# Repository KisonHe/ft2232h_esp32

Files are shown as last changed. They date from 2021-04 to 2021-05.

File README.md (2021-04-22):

# ft2232h_esp32

How to use make this tool?

1. First, get your PCB.
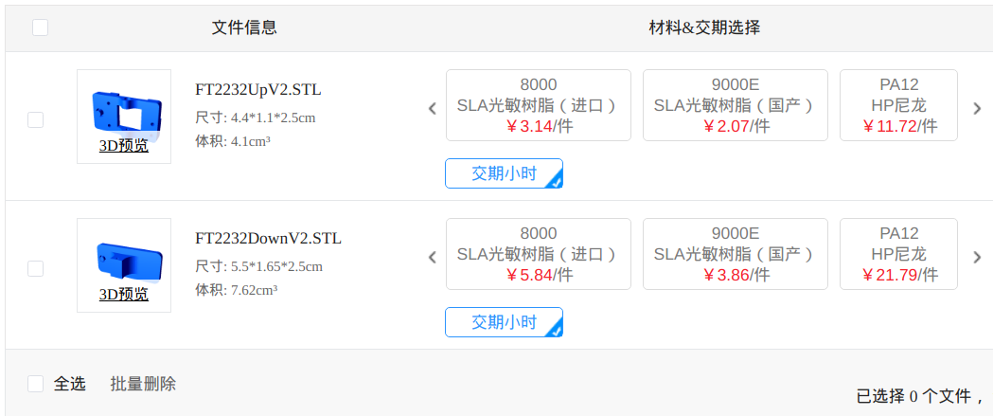
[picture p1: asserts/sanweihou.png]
sanweihou
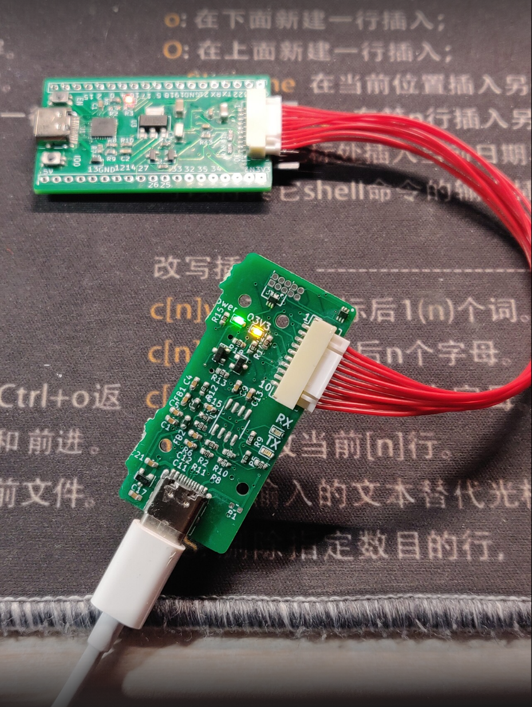
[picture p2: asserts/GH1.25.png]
GH1.25
2. Print the 3D part. STL and SolidWorks2016 files are available. You can go to sanweihou for 3D printing, the cost is incredibly low, Less than 2 dollars! If you decide not to print the 3D part, you can't use pins. However GH1.25 cables are still available as the photo shows 
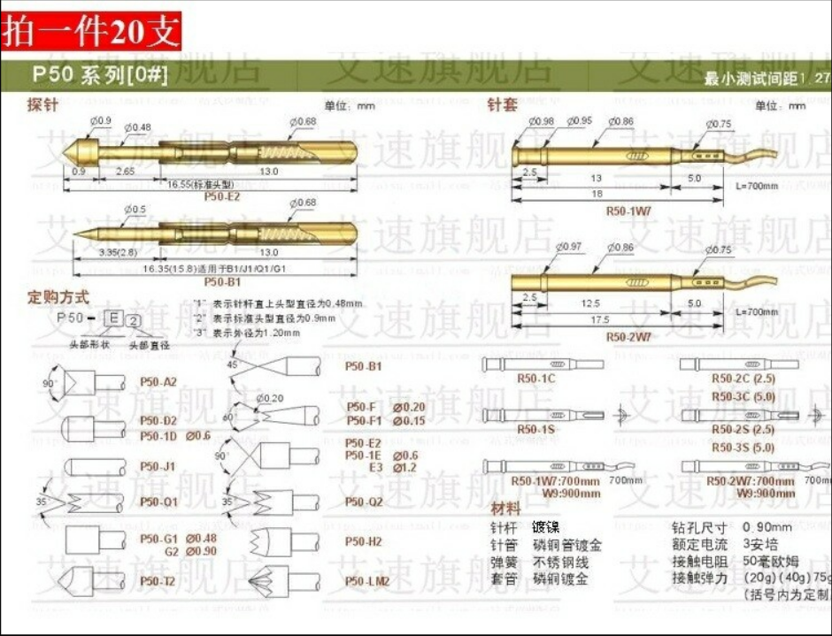
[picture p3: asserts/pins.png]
Example pins
3. Or, get the pins, under board, screws and put them together. When you are buying the pins, **be careful about their radius**. Double check if the PCB and the pins can fit in.
4. How it looks.

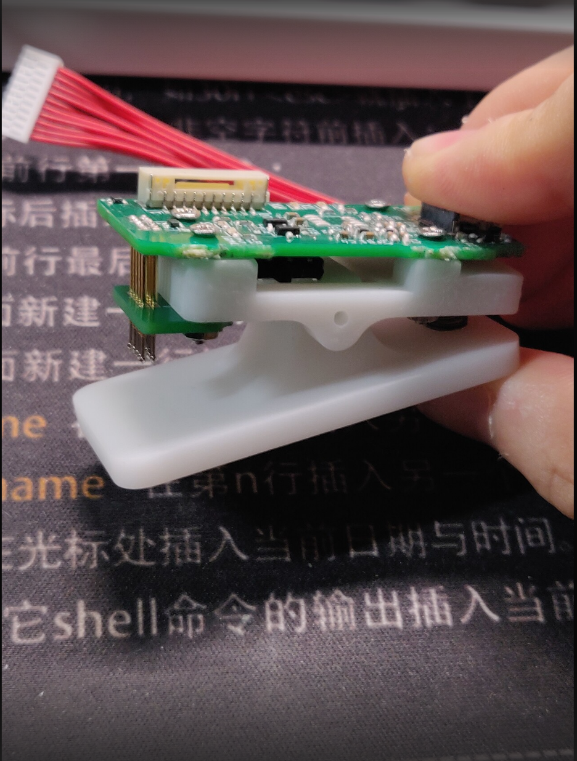
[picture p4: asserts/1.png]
Example pic1

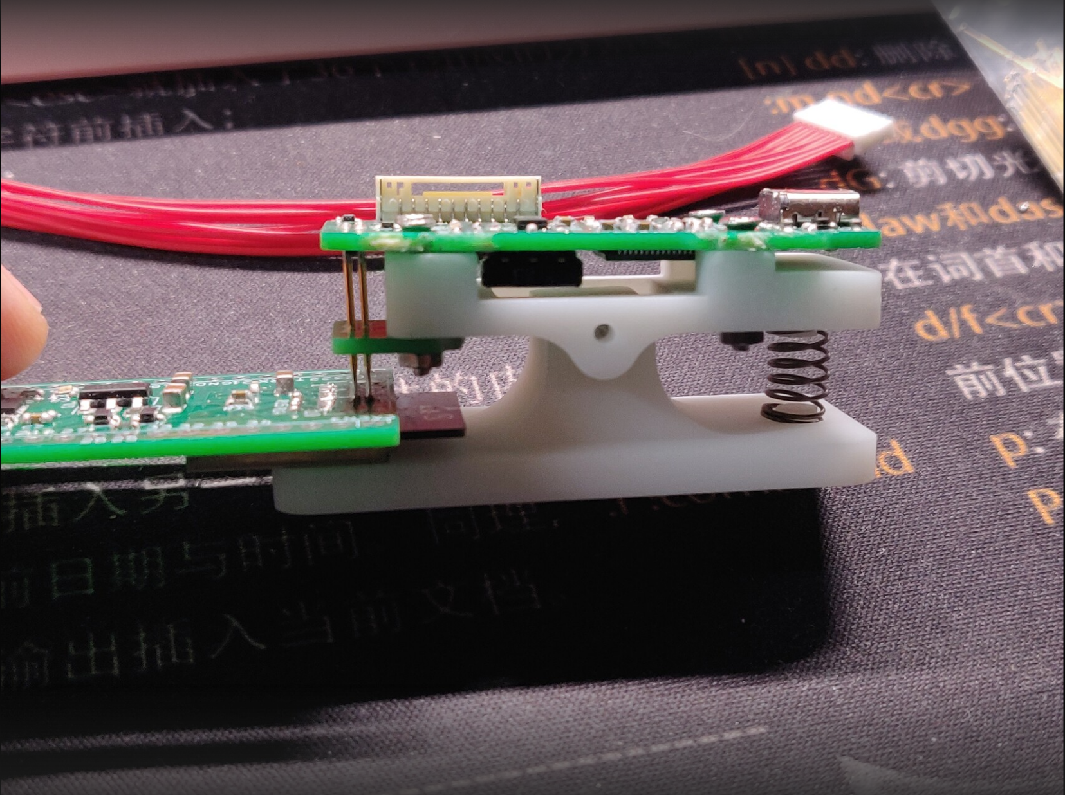
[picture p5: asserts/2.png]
Example pic2


Last, please don't forget the ESDs(USBLC6-2P6). If you don't mount them, it is possible for you to break your ft2232 after some thousands times of connecting. Please Search Google for more info about why ESD is important.

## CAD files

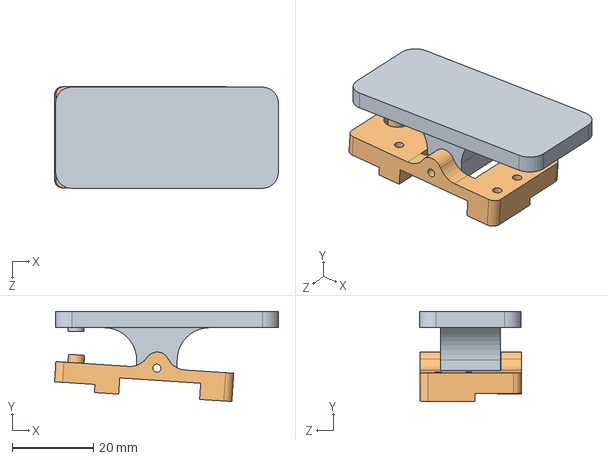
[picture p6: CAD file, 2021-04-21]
ft2232.SLDASM
55.3 x 22.2 x 25.1 mm
FT2232Down
FT2232Up

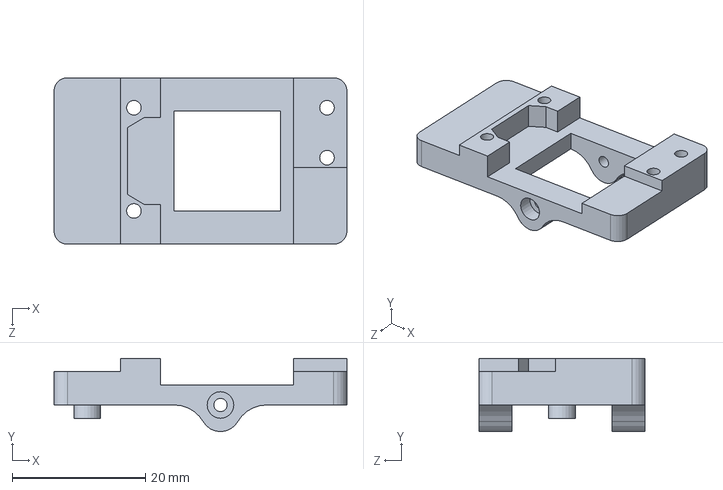
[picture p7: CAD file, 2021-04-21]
FT2232Up.SLDPRT
44.0 x 11.0 x 25.0 mm

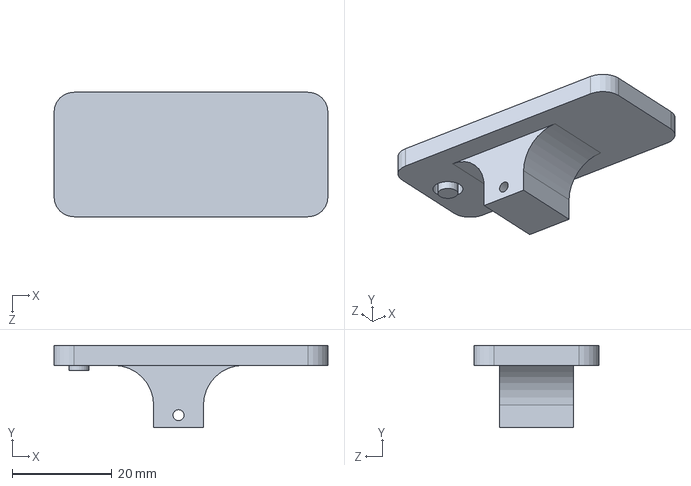
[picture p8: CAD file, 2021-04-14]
FT2232Down.SLDPRT
55.0 x 16.5 x 25.0 mm

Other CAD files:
FT2232Down.STL
FT2232Up.STL

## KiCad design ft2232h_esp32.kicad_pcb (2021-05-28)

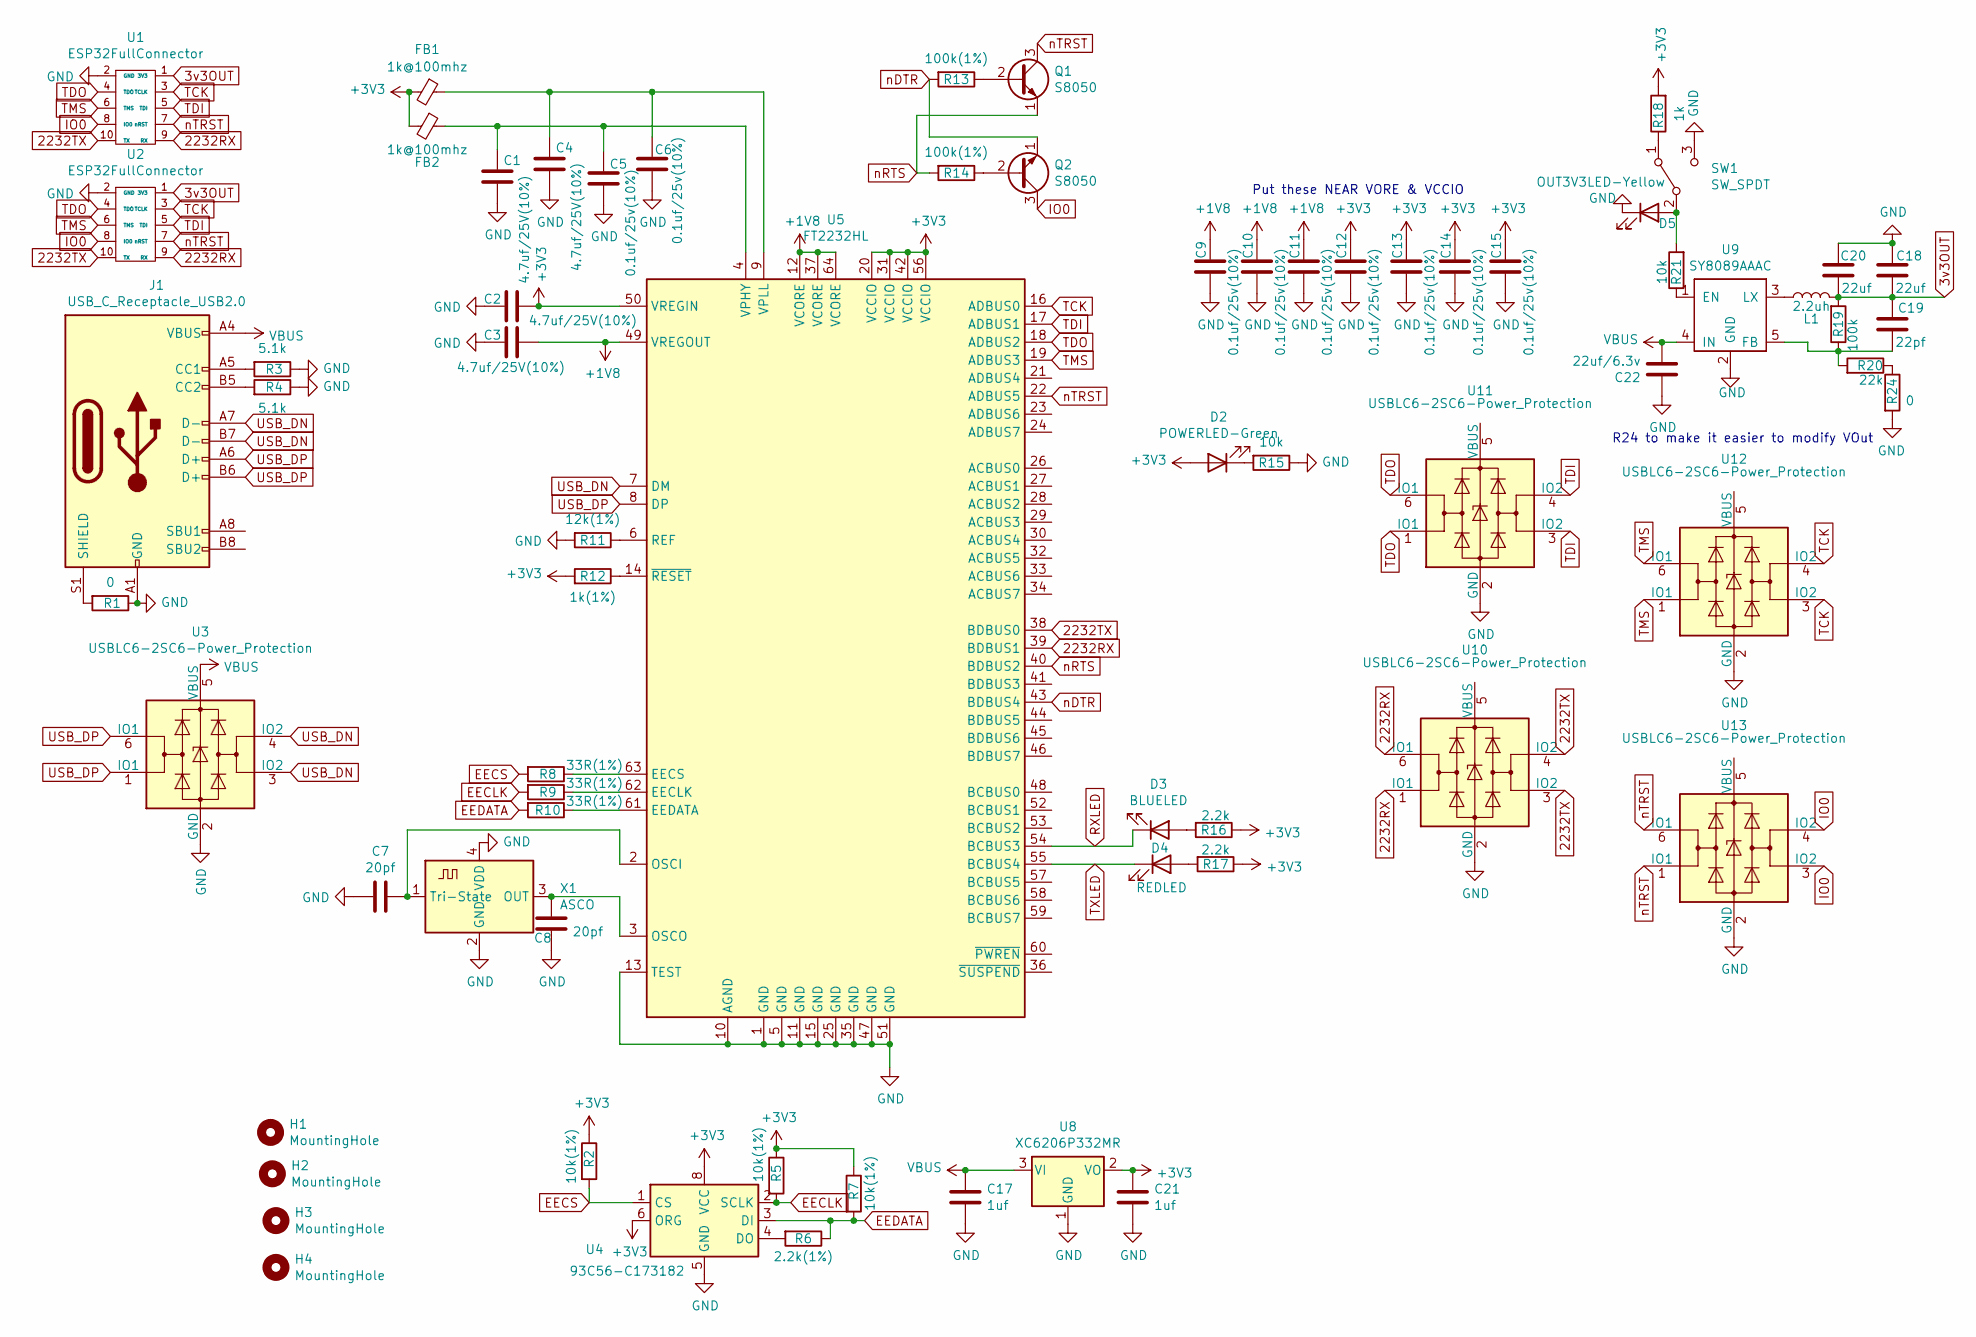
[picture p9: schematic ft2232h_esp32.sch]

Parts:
C1, C2, C3, C4: 4.7uf/25V(10%); C_0603_1608Metric; LCSC C19666
C5, C6, C9, C10, C11, C12, C13, C14, C15: 0.1uf/25v(10%); C_0603_1608Metric; LCSC C14663
C7, C8: 20pf; C_0603_1608Metric; LCSC C1648
C17, C21: 1uf; C_0603_1608Metric; LCSC C15849
C18, C20: 22uf; C_0603_1608Metric; LCSC C59461
C19: 22pf; C_0603_1608Metric; LCSC C1653
C22: 22uf/6.3v; C_1206_3216Metric; LCSC C59461
D2: POWERLED-Green; LED_0603_1608Metric; LCSC C72043
D3: BLUELED; LED_0603_1608Metric; LCSC C72041
D4: REDLED; LED_0603_1608Metric; LCSC C2286
D5: OUT3V3LED-Yellow; LED_0603_1608Metric; LCSC C72038
FB1, FB2: 1k@100mhz; R_0603_1608Metric
H1, H2, H3, H4: MountingHole; MountingHole_2.2mm_M2
J1: USB_C_Receptacle_USB2.0; USB_C_Receptacle_HRO_TYPE-C-31-M-12
L1: 2.2uh; L_1008_2520Metric
Q1, Q2: S8050; SOT-23; LCSC C2150
R1, R24: 0; R_0603_1608Metric; LCSC C21189
R2, R5, R7: 10k(1%); R_0603_1608Metric; LCSC C25804
R3, R4: 5.1k; R_0603_1608Metric; LCSC C23186
R6: 2.2k(1%); R_0603_1608Metric; LCSC C4190
R8, R9, R10: 33R(1%); R_0603_1608Metric; LCSC C23140
R11: 12k(1%); R_0603_1608Metric; LCSC C22790
R12: 1k(1%); R_0603_1608Metric; LCSC C21190
R13, R14: 100k(1%); R_0603_1608Metric; LCSC C25803
R15, R21: 10k; R_0603_1608Metric; LCSC C25804
R16, R17: 2.2k; R_0603_1608Metric; LCSC C4190
R18: 1k; R_0603_1608Metric; LCSC C21190
R19: 100k; R_0603_1608Metric; LCSC C25803
R20: 22k; R_0603_1608Metric; LCSC C31850
SW1: SW_SPDT; SW_SPDT_CK-JS102011SAQN
U1: ESP32FullConnector; jtag1.27-10
U2: ESP32FullConnector; Molex_CLIK-Mate_502382-1070_1x10-1MP_P1.25mm_Vertical
U3, U10, U11, U12, U13: USBLC6-2SC6-Power_Protection; USBLC6-2P6-SOT666
U4: 93C56-C173182; SOP-8_3.76x4.96mm_P1.27mm
U5: FT2232HL; LQFP-64_10x10mm_P0.5mm
U8: XC6206P332MR; SOT-23
U9: SY8089AAAC; TSOT-23-5
X1: ASCO; Oscillator_SMD_Fordahl_DFAS15-4Pin_5.0x3.2mm

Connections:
3v3OUT: C18.2, C19.1, C20.2, L1.1, R19.2, U1.1 (3V3), U2.1 (3V3)
2232RX: U1.9 (RX), U2.9 (RX), U5.39 (BDBUS1), U10.1 (IO1), U10.6 (IO1)
2232TX: U1.10 (TX), U2.10 (TX), U5.38 (BDBUS0), U10.3 (IO2), U10.4 (IO2)
+1V8: C3.1, C9.1, C10.1, C11.1, U5.12 (VCORE), U5.37 (VCORE), U5.49 (VREGOUT), U5.64 (VCORE)
+3V3: C2.1, C12.1, C13.1, C14.1, C15.1, C21.2, D2.2 (A), FB1.2, FB2.2, R2.1, R5.1, R7.1, R12.2, R16.1, R17.1, R18.2, U4.6 (ORG), U4.8 (VCC), U5.20 (VCCIO), U5.31 (VCCIO), U5.42 (VCCIO), U5.50 (VREGIN), U5.56 (VCCIO), U8.2 (VO)
EECLK: R5.2, R9.2, U4.2 (SCLK)
EECS: R2.2, R8.2, U4.1 (CS)
EEDATA: R6.1, R7.2, R10.2, U4.3 (DI)
GND: C1.2, C2.2, C3.2, C4.2, C5.2, C6.2, C7.2, C8.2, C9.2, C10.2, C11.2, C12.2, C13.2, C14.2, C15.2, C17.1, C18.1, C20.1, C21.1, C22.1, D5.1 (K), J1.A1 (GND), J1.A12 (GND), J1.B1 (GND), J1.B12 (GND), R1.1, R3.1, R4.1, R11.2, R15.1, R24.2, SW1.3 (C), U1.2 (GND), U2.2 (GND), U3.2 (GND), U4.5 (GND), U5.1 (GND), U5.5 (GND), U5.10 (AGND), U5.11 (GND), U5.13 (TEST), U5.15 (GND), U5.25 (GND), U5.35 (GND), U5.47 (GND), U5.51 (GND), U8.1 (GND), U9.2 (GND), U10.2 (GND), U11.2 (GND), U12.2 (GND), U13.2 (GND), X1.2 (GND), X1.4 (VDD)
IO0: Q2.3 (C), U1.8 (IO0), U2.8 (IO0), U13.3 (IO2), U13.4 (IO2)
unnamed: C1.1, C5.1, FB2.1, U5.4 (VPHY)
unnamed: C4.1, C6.1, FB1.1, U5.9 (VPLL)
unnamed: C7.1, U5.2 (OSCI), X1.1 (Tri-State)
unnamed: C8.1, U5.3 (OSCO), X1.3 (OUT)
unnamed: C19.2, R19.1, R20.2, U9.5 (FB)
unnamed: D2.1 (K), R15.2
unnamed: D3.2 (A), R16.2
unnamed: D4.2 (A), R17.2
unnamed: D5.2 (A), R21.2, SW1.2 (B)
unnamed: J1.A5 (CC1), R3.2
unnamed: J1.B5 (CC2), R4.2
unnamed: J1.S1 (SHIELD), R1.2
unnamed: L1.2, U9.3 (LX)
unnamed: Q1.2 (B), R13.1
unnamed: Q2.2 (B), R14.1
unnamed: R6.2, U4.4 (DO)
unnamed: R8.1, U5.63 (EECS)
unnamed: R9.1, U5.62 (EECLK)
unnamed: R10.1, U5.61 (EEDATA)
unnamed: R11.1, U5.6 (REF)
unnamed: R12.1, U5.14 (~RESET)
unnamed: R18.1, SW1.1 (A)
unnamed: R20.1, R24.1
unnamed: R21.1, U9.1 (EN)
RXLED: D3.1 (K), U5.54 (BCBUS3)
TCK: U1.3 (TCLK), U2.3 (TCLK), U5.16 (ADBUS0), U12.3 (IO2), U12.4 (IO2)
TDI: U1.5 (TDI), U2.5 (TDI), U5.17 (ADBUS1), U11.3 (IO2), U11.4 (IO2)
TDO: U1.4 (TDO), U2.4 (TDO), U5.18 (ADBUS2), U11.1 (IO1), U11.6 (IO1)
TMS: U1.6 (TMS), U2.6 (TMS), U5.19 (ADBUS3), U12.1 (IO1), U12.6 (IO1)
TXLED: D4.1 (K), U5.55 (BCBUS4)
USB_DN: J1.A7 (D-), J1.B7 (D-), U3.3 (IO2), U3.4 (IO2), U5.7 (DM)
USB_DP: J1.A6 (D+), J1.B6 (D+), U3.1 (IO1), U3.6 (IO1), U5.8 (DP)
VBUS: C17.2, C22.2, J1.A4 (VBUS), J1.A9 (VBUS), J1.B4 (VBUS), J1.B9 (VBUS), U3.5 (VBUS), U8.3 (VI), U9.4 (IN)
nDTR: Q2.1 (E), R13.2, U5.43 (BDBUS4)
nRTS: Q1.1 (E), R14.2, U5.40 (BDBUS2)
nTRST: Q1.3 (C), U1.7 (nRST), U2.7 (nRST), U5.22 (ADBUS5), U13.1 (IO1), U13.6 (IO1)

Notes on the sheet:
Put these NEAR VORE & VCCIO
R24 to make it easier to modify VOut

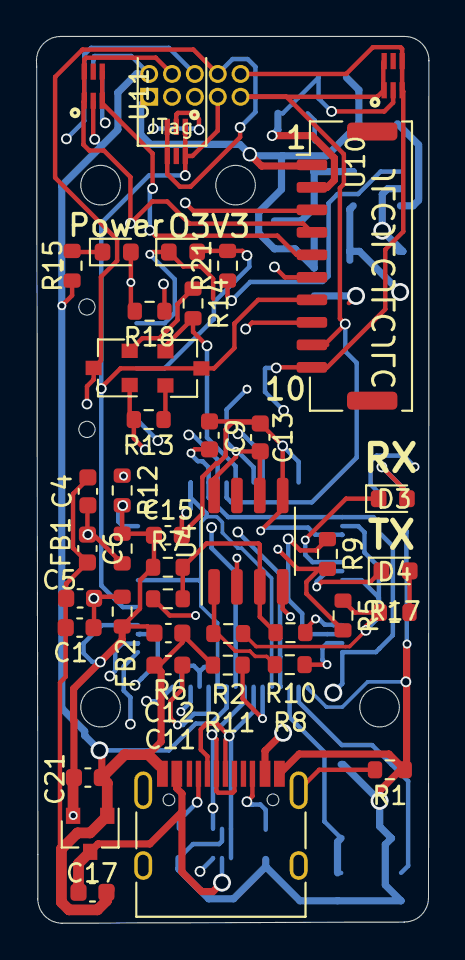
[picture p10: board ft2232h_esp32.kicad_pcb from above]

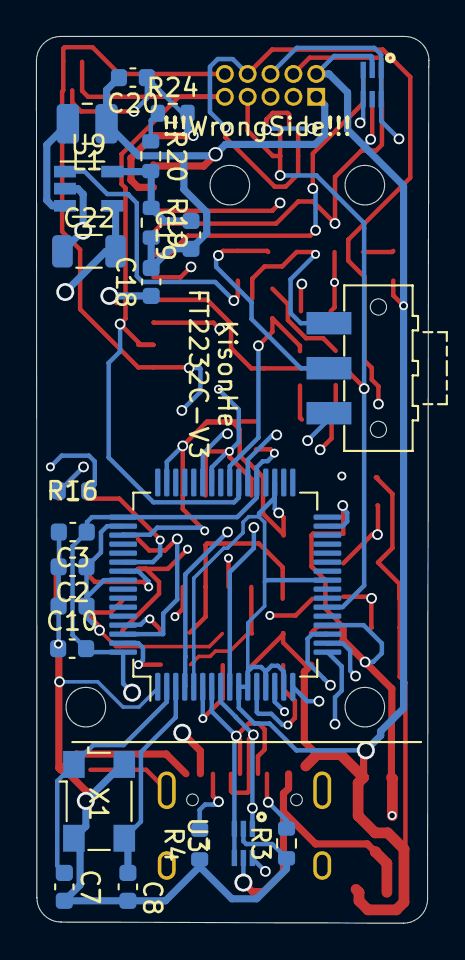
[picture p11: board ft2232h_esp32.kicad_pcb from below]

Board: 4 copper layers, 21.8 x 49.3 mm, 70 parts (23 on the bottom side), 46 nets.

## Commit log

2021-04-10 Fix Crystal
    [ft2232h_esp32.kicad_pcb, ft2232h_esp32.sch]
2021-04-13 Add LCSC
    [ft2232h_esp32.sch]
2021-04-14 Add SLDPRT;Fix PCB Parts interference
    [FT2232Down.SLDPRT, FT2232Up.SLDPRT, ft2232.SLDASM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]
2021-04-21 Detach Under Board
    [FT2232Down.STL, FT2232Up.SLDPRT, FT2232Up.STL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]
2021-04-21 Modify Silk
    [UnderBoard.kicad_pcb, ft2232h_esp32.kicad_pcb]
